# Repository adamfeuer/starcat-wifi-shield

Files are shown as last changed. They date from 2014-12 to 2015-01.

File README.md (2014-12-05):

Wifi Shield for Arduino Due
===========================

This is a wifi shield for Arduino Due, providing a connector to mount an
[Arietta SAM9G Linux module](http://www.acmesystems.it/arietta).

The purpose of this shield is to connect the Arduino Due to the Internet
via a USB connection to Linux running on the wifi-enabled Arietta board.

Eventually I would like to get OpenWRT running on the Arietta board instead of Debian,
so users can run a software stack similar to the [Arduino Yún](http://arduino.cc/en/Main/ArduinoBoardYun?from=Products.ArduinoYUN).

* [Arietta shield schematic](https://github.com/adamfeuer/arietta-shield/blob/master/arietta-shield.pdf)
* [Arietta shield PCB layout](https://github.com/adamfeuer/arietta-shield/blob/master/arietta-shield.png)
* [Arietta shield gerber files](https://github.com/adamfeuer/arietta-shield/blob/master/cam/arietta-shield-oshpark-files-2014-12-01-1848.zip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) - suitable for submitting to [OSH Park](https://oshpark.com/).

If there's enough interest, I may decide to manufacture this board;
if you'd like to be notified if that happens, [you can sign up here](http://starcat.io/arietta-shield/).

Until then, you can make your own. Unfortunately, I can't provide support for it.
Good luck!

Features
========

* USB type A female connector that powers the Arietta module.
* A short male micro-B to male type A USB cable connects the wifi shield to the Arduino Due.
 * [5 inch male micro-B to male A cable](http://www.amazon.com/gp/product/B00JX1260Y/) - this is inexpensive and works well
 * Provides USB 2.0 480Mbps connection to the Arduino Due using equal-length differential traces.

Notes
=====

* The schematic and PCB layout were done in [Eagle CAD 6.5](http://www.cadsoftusa.com/).
* The PCB is a 2-layer board.
* This the the USB connector used - [TE Connectivity USB A Female](http://www.digikey.com/product-search/en?KeyWords=A31726-ND&WT.z_header=search_go) - manufacturer part number 292303-1
* Arduino shield connectors are from [4UCon](http://www.4uconnector.com/), ordered from eBay sellers.

License
=======

[Creative Commons By-Attribution ShareAlike 4.0](https://creativecommons.org/licenses/by-sa/4.0/)

Comments
========

If you have questions, comments, or improvements, I would love to know them!

cheers <br>
adam <br>
Adam Feuer <br>
Seattle, WA, USA <br>
adam@adamfeuer.com <br>
http://adamfeuer.com <br>

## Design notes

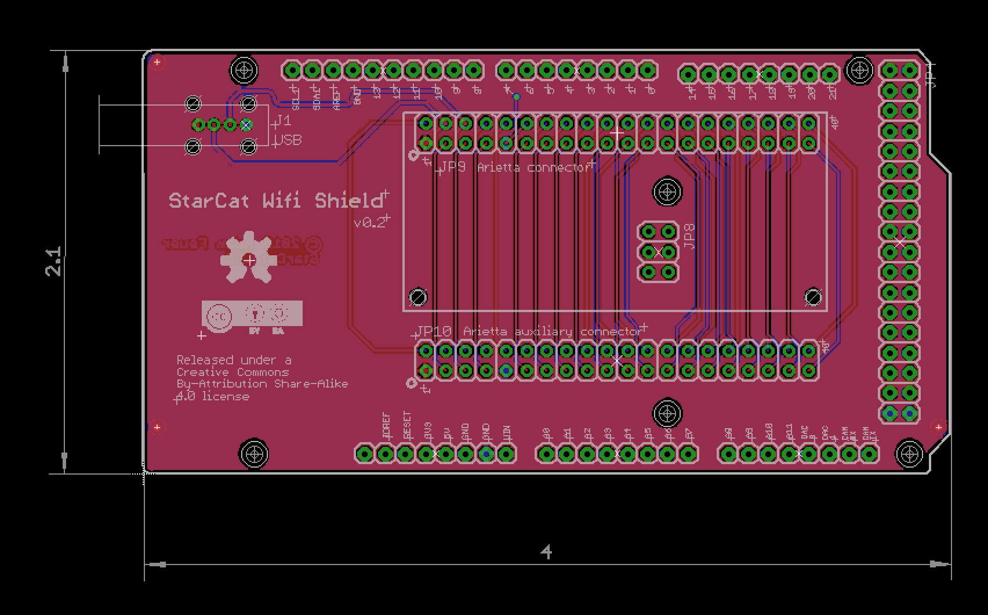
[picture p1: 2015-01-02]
wifi-shield.png

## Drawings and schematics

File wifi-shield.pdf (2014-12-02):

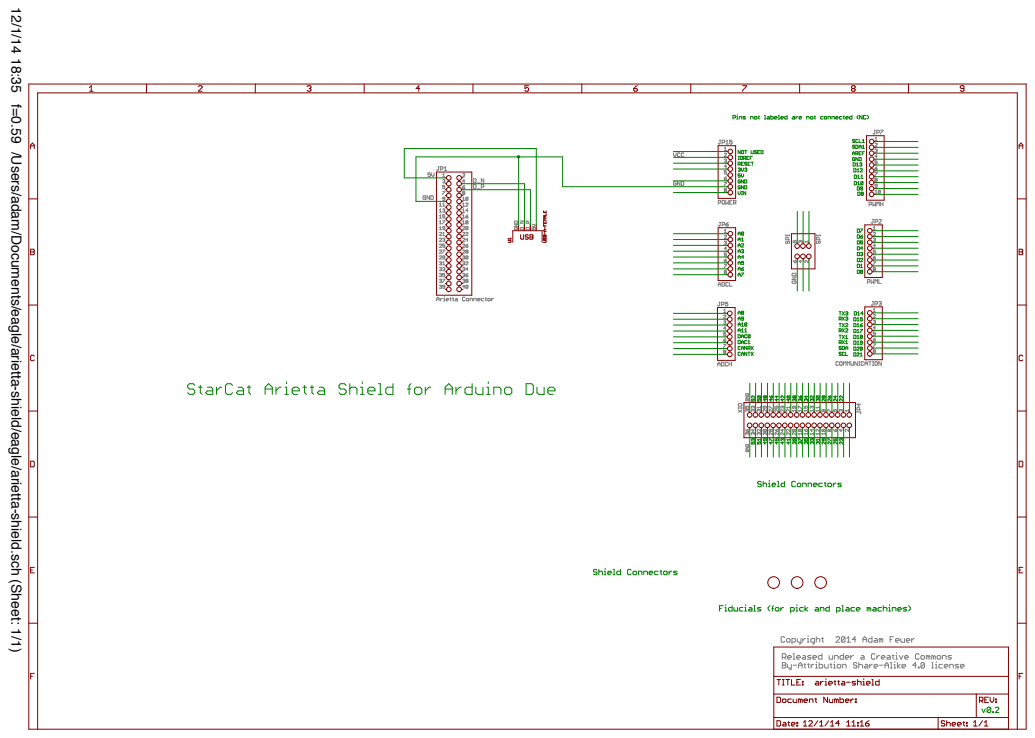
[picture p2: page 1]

12/1/14 18:35 f=0.59 /Users/adam/Documents/eagle/arietta-shield/eagle/arietta-shield.sch (Sheet: 1/1)

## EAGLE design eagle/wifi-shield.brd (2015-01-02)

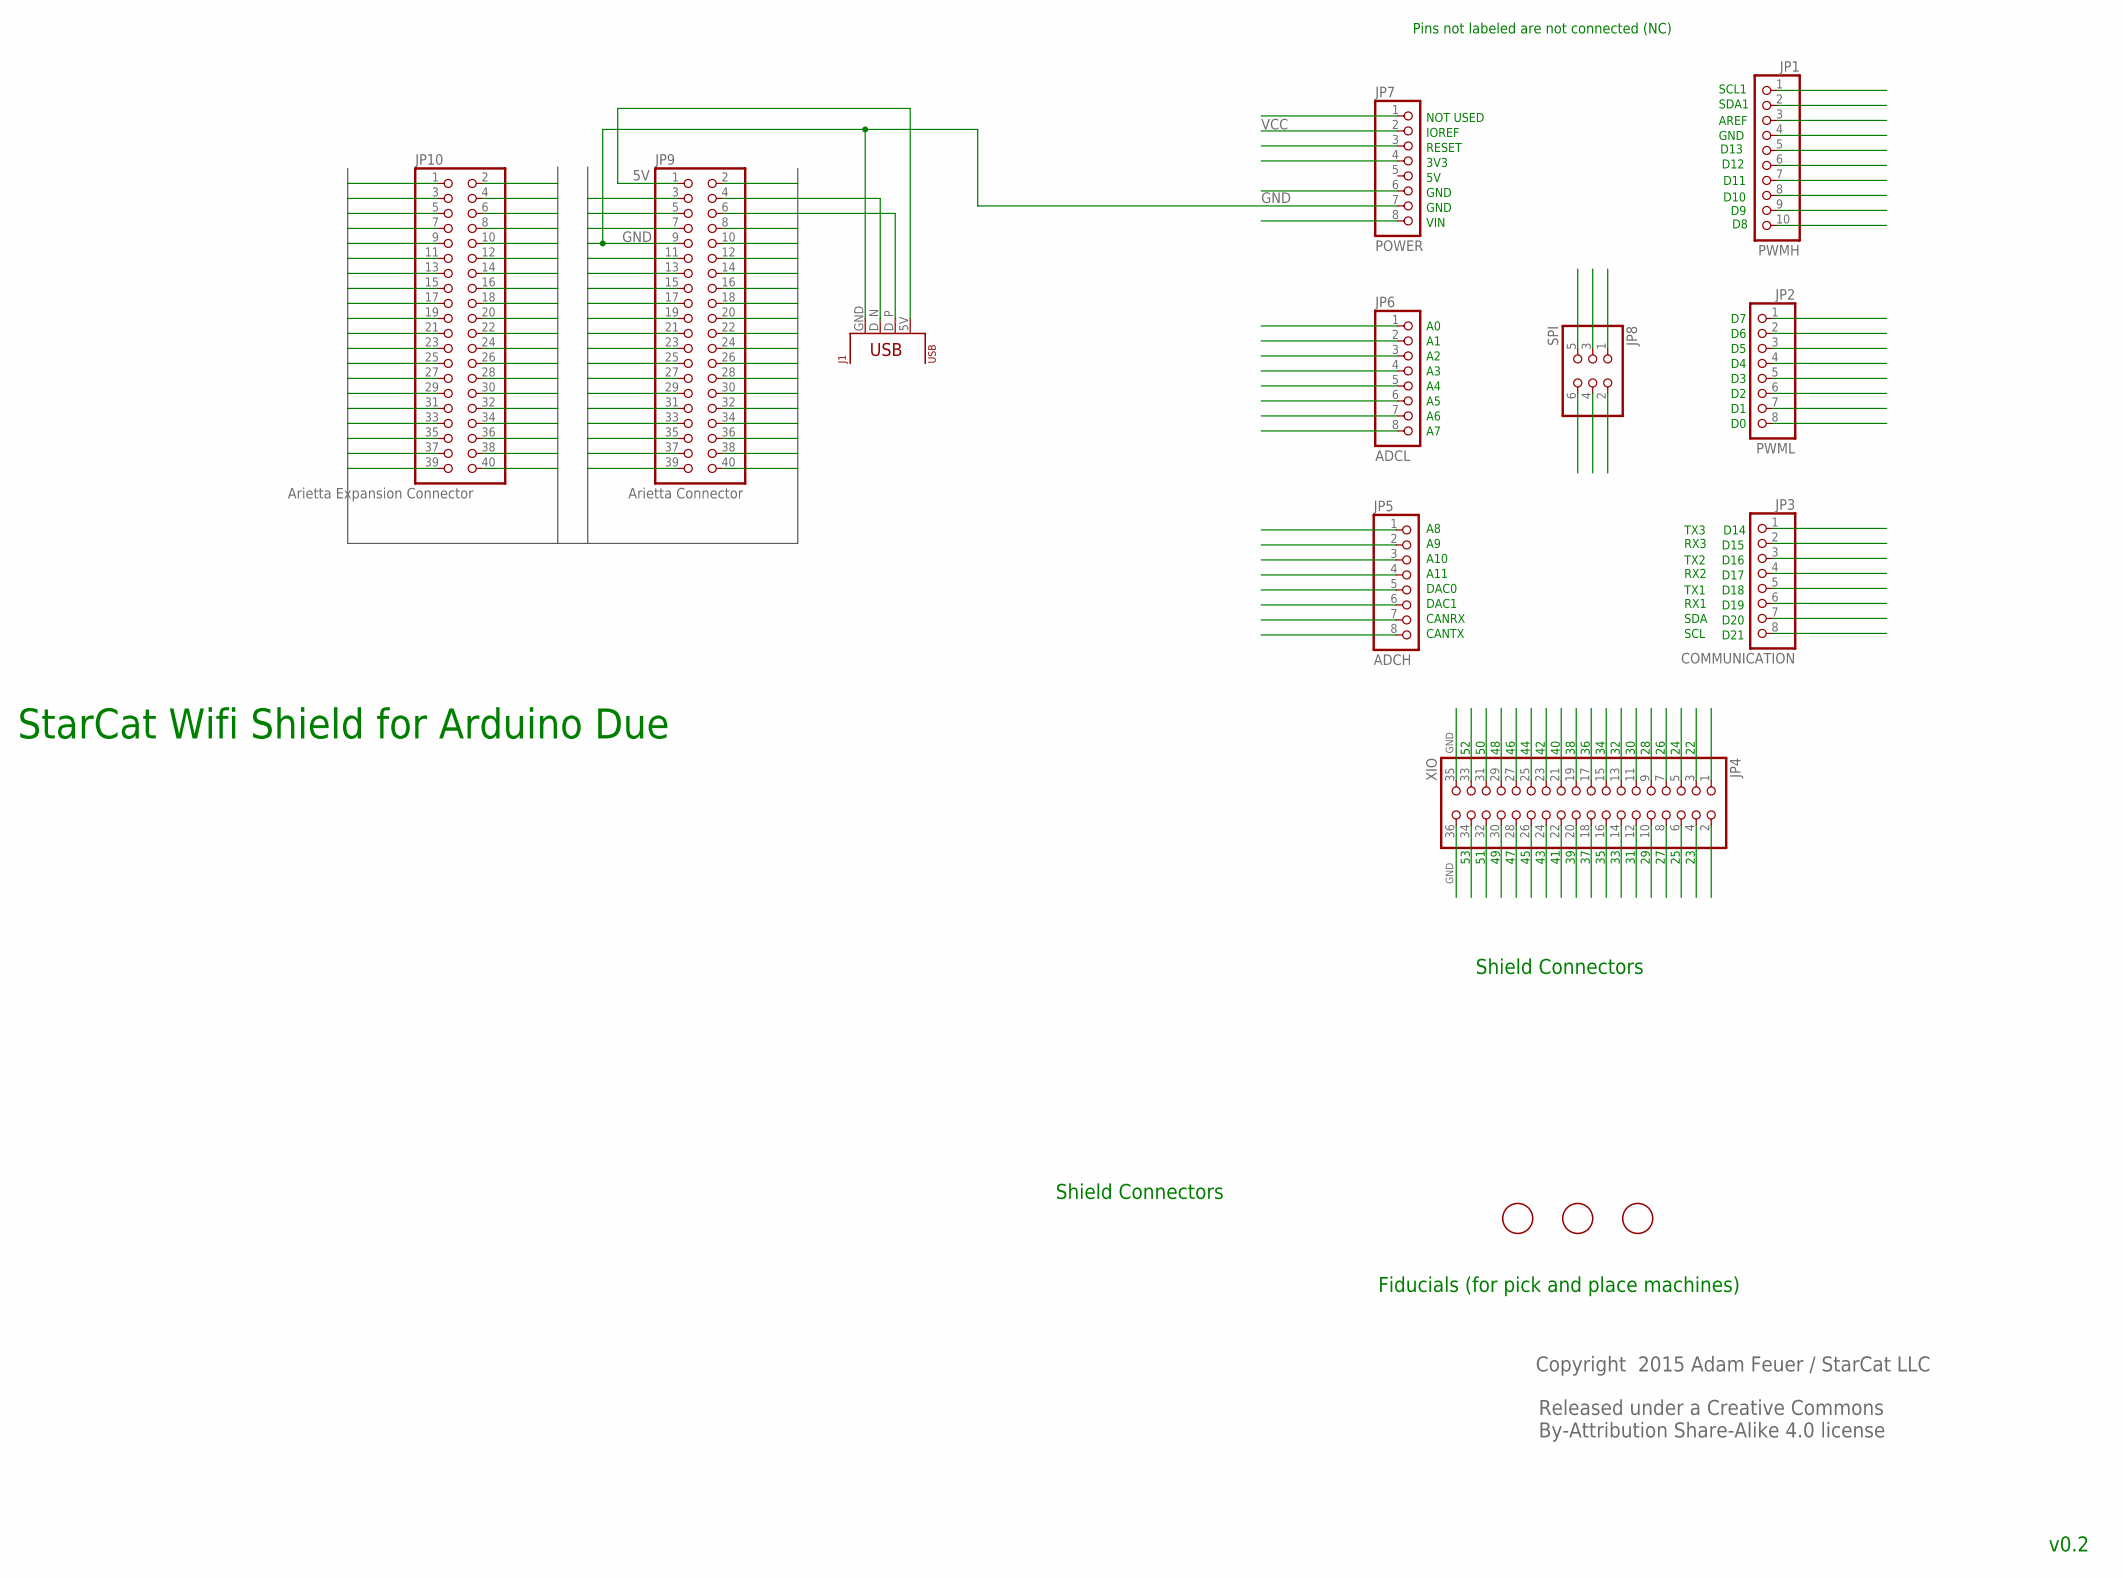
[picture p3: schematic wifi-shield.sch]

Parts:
J1: USB; USB-A-FEMALE-RIGHT-ANGLE
JP1: PWMH; 1X10
JP2: PWML; 1X08
JP3: COMMUNICATION; 1X08
JP4: XIO; 2X18
JP5: ADCH; 1X08
JP6: ADCL; 1X08
JP7: POWER; 1X08
JP8: SPI; 2X03
JP9: Arietta Connector; 2X20
JP10: Arietta Expansion Connector; 2X20
U$2, U$5, U$6: FIDUCIAL; FIDUCIAL_1MM

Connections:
5V: J1.5V, JP9.1, JP10.1
D2: JP9.2, JP10.2
D3: JP9.3, JP10.3
D5: JP9.5, JP10.5
D7: JP9.7, JP10.7
D8: JP9.8, JP10.8
D10: JP9.10, JP10.10
D11: JP9.11, JP10.11
D12: JP9.12, JP10.12
D13: JP9.13, JP10.13
D14: JP9.14, JP10.14
D15: JP9.15, JP10.15
D16: JP9.16, JP10.16
D17: JP9.17, JP10.17
D18: JP9.18, JP10.18
D19: JP9.19, JP10.19
D20: JP9.20, JP10.20
D21: JP9.21, JP10.21
D22: JP9.22, JP10.22
D23: JP9.23, JP10.23
D24: JP9.24, JP10.24
D25: JP9.25, JP10.25
D26: JP9.26, JP10.26
D27: JP9.27, JP10.27
D28: JP9.28, JP10.28
D29: JP9.29, JP10.29
D30: JP9.30, JP10.30
D31: JP9.31, JP10.31
D32: JP9.32, JP10.32
D33: JP9.33, JP10.33
D34: JP9.34, JP10.34
D35: JP9.35, JP10.35
D36: JP9.36, JP10.36
D37: JP9.37, JP10.37
D38: JP9.38, JP10.38
D39: JP9.39, JP10.39
D40: JP9.40, JP10.40
D43: JP4.24
D45: JP4.26
D_N: J1.D_N, JP9.4, JP10.4
D_P: J1.D_P, JP9.6, JP10.6
GND: J1.GND, JP4.35, JP4.36, JP7.7, JP9.9, JP10.9
GND1: JP8.6
RESET: JP8.5
SPI0_MISO: JP8.1
SPI0_MOSI: JP8.4
SPI0_SCK: JP8.3
VCC: JP7.2
VCC_5V: JP8.2

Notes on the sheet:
Released under a Creative Commons By-Attribution Share-Alike 4.0 license
Copyright 2015 Adam Feuer / StarCat LLC
Shield Connectors
A10
A11
DAC0
DAC1
CANRX
CANTX
NOT USED
IOREF
RESET
3V3
GND
VIN
Fiducials (for pick and place machines)
Pins not labeled are not connected (NC)
SCL1
SDA1
AREF
D13
D12
D11
D10
D14
D15
D16
D17
D18
D19
D20
D21
TX2
RX2
TX3
RX3
TX1
RX1
SDA
SCL

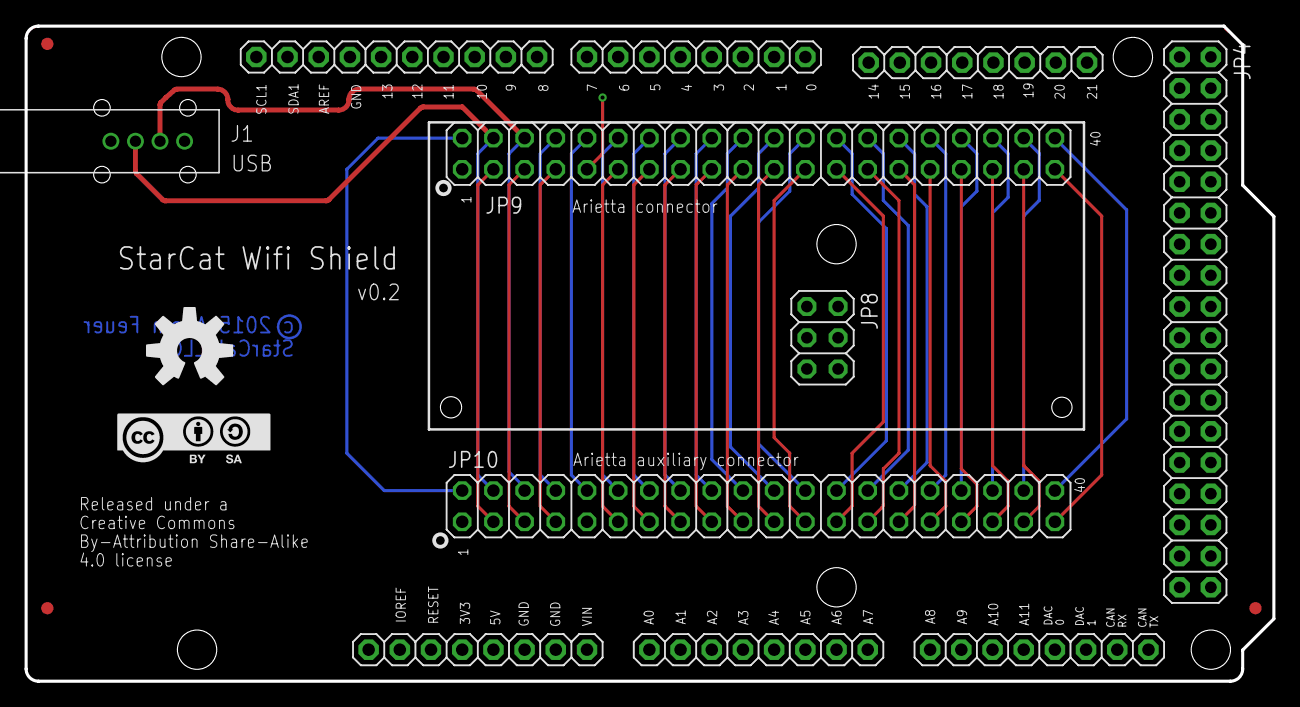
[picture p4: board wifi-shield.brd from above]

Board: 2 copper layers, 101.6 x 53.3 mm, 16 parts (0 on the bottom side), 40 nets.

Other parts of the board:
U$1: OSHW-LOGO-L
U$8: CC-BY-SA

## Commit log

2014-12-02 added unpopulated SPI and rear connectors
    - 5V now only connected to USB now, not shield connector,
    enabling connection to another computer when connected to
    the Arduino Due
    [arietta-shield.brd, arietta-shield.sch]
2014-12-02 adding schematic PDF and board PNG
2014-12-02 added board schematic and PCB PNG to README
2014-12-02 clarified USB differential traces in README
2014-12-02 adding gerber files suitable for OSH Park
2014-12-02 adding gerber files package to README
2014-12-04 renamed arietta shield to wifi shield
    - due to potential trademark issues
    [wifi-shield.brd, wifi-shield.sch, wifi-shield.xlsx]
2014-12-05 updated PCB picture with board name change
2015-01-02 moved BOM to separate repo
    [wifi-shield.xlsx]
2015-01-02 added Arietta expansion connector
    - to schematic, but not routed yet
    [wifi-shield.brd, wifi-shield.sch]
2015-01-02 corrected and routed Arietta auxiliary connector
    - net classes are correct
    - ERC and DRC pass
    [wifi-shield.brd, wifi-shield.sch]
2015-01-02 updated board picture

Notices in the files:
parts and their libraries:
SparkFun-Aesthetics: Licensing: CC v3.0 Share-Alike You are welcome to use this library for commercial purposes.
